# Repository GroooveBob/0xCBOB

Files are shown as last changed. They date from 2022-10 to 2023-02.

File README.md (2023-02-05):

# 0xCBOB
ortho board in static style

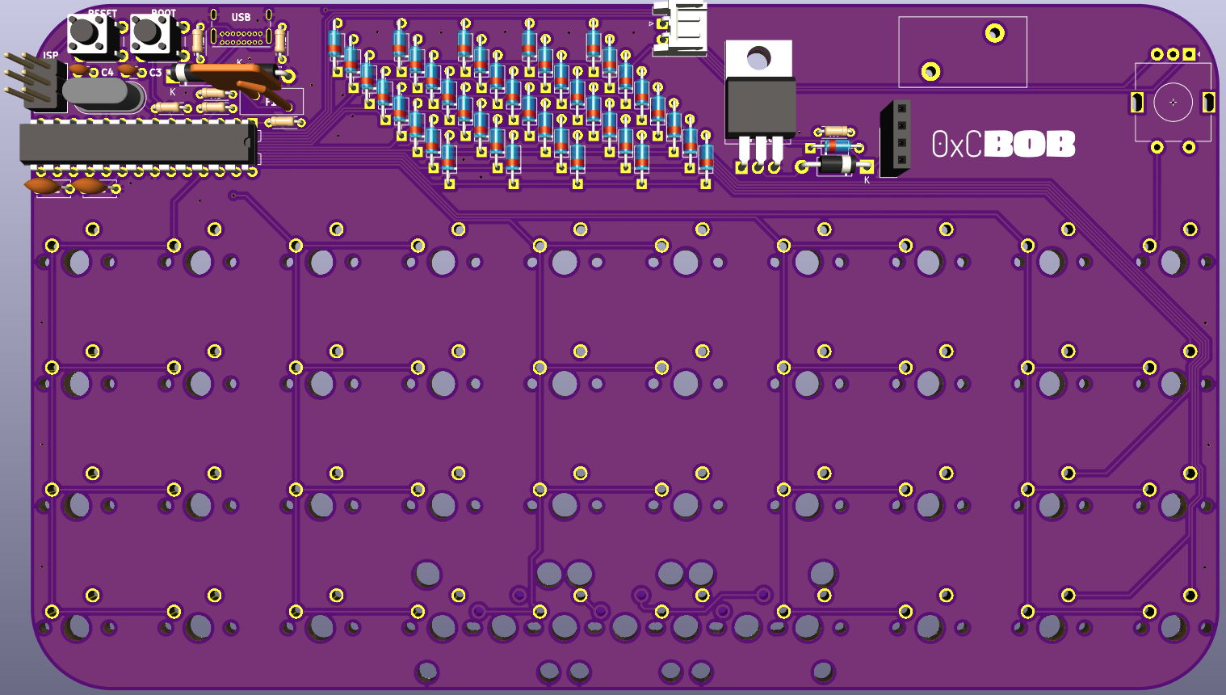
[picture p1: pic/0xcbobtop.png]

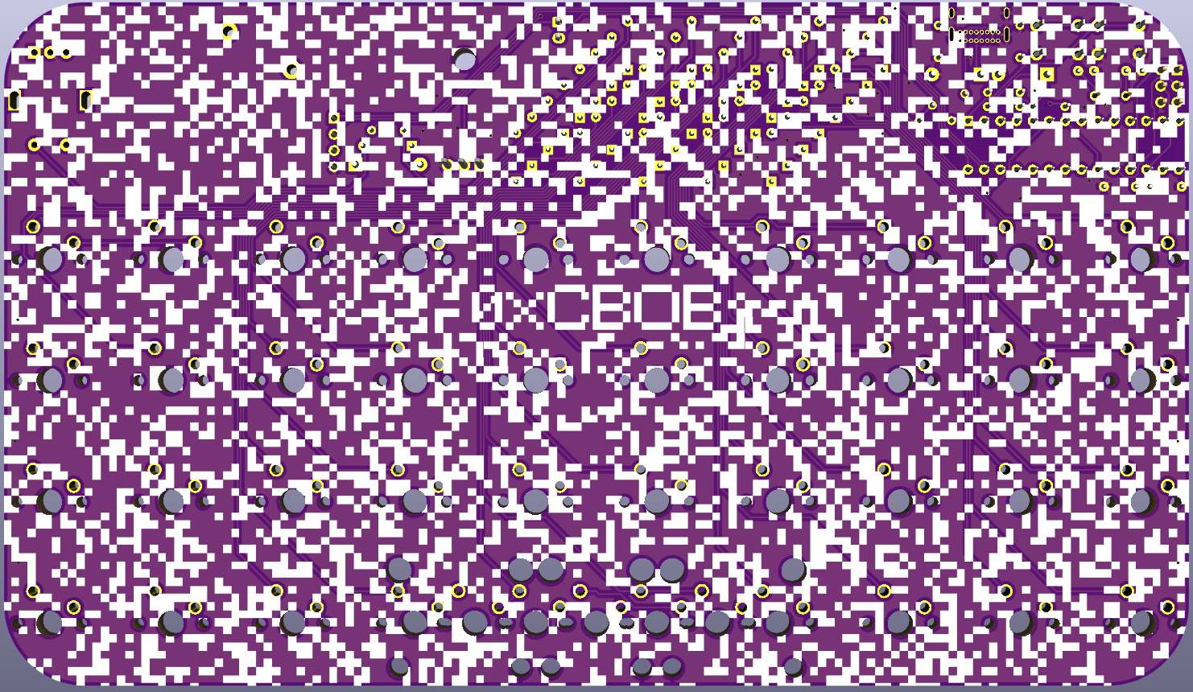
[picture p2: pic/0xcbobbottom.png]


[the wonderful dreipunkteinsvier made the QMK Firmware](https://github.com/dreipunkteinsvier/qmk-config-0xCBOB)

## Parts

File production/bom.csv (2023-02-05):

Designator | Footprint | Quantity | Value | LCSC Part #
SW40 | SW_Cherry_MX_1.00u_PCB | 1 | SW_Push_45deg
D9 | D_DO-35_SOD27_P7.62mm_Horizontal | 1 | 1N4148
SW24 | SW_Cherry_MX_1.00u_PCB | 1 | SW_Push_45deg
D34 | D_DO-35_SOD27_P7.62mm_Horizontal | 1 | 1N4148
SW9 | SW_Cherry_MX_1.00u_PCB | 1 | SW_Push_45deg
SW15 | SW_Cherry_MX_1.00u_PCB | 1 | SW_Push_45deg
SW45 | MXOnly-2U-ReversedStabilizers-NoLED | 1 | SW_Push_45deg
D40 | D_DO-35_SOD27_P7.62mm_Horizontal | 1 | 1N4148
D10 | D_DO-35_SOD27_P7.62mm_Horizontal | 1 | 1N4148
D26 | D_DO-35_SOD27_P7.62mm_Horizontal | 1 | 1N4148
J1 | USB_C_Receptacle_GCT_USB4085 | 1 | USB
C3 | C_Disc_D3.0mm_W1.6mm_P2.50mm | 1 | 20pF
SW32 | SW_Cherry_MX_1.00u_PCB | 1 | SW_Push_45deg
OLED1 | PinSocket_1x04_P2.54mm_Vertical | 1 | OLED
D8 | D_DO-35_SOD27_P7.62mm_Horizontal | 1 | 1N4148
D32 | D_DO-35_SOD27_P7.62mm_Horizontal | 1 | 1N4148
D33 | D_DO-35_SOD27_P7.62mm_Horizontal | 1 | 1N4148
R5 | R_Axial_DIN0204_L3.6mm_D1.6mm_P5.08mm_Horizontal | 1 | 75
SW18 | SW_Cherry_MX_1.00u_PCB | 1 | SW_Push_45deg
R7 | R_Axial_DIN0204_L3.6mm_D1.6mm_P5.08mm_Horizontal | 1 | 2.2K
Y1 | Crystal_HC49-4H_Vertical | 1 | 16MHz
SW27 | SW_Cherry_MX_1.00u_PCB | 1 | SW_Push_45deg
SW34 | SW_Cherry_MX_1.00u_PCB | 1 | SW_Push_45deg
D37 | D_DO-35_SOD27_P7.62mm_Horizontal | 1 | 1N4148
SW31 | SW_Cherry_MX_1.00u_PCB | 1 | SW_Push_45deg
D42 | D_DO-35_SOD27_P7.62mm_Horizontal | 1 | 1N4148
SW12 | SW_Cherry_MX_1.00u_PCB | 1 | SW_Push_45deg
SW43 | MXOnly-2U-ReversedStabilizers-NoLED | 1 | SW_Push_45deg
D20 | D_DO-35_SOD27_P7.62mm_Horizontal | 1 | 1N4148
SW16 | SW_Cherry_MX_1.00u_PCB | 1 | SW_Push_45deg
SW38 | SW_Cherry_MX_1.00u_PCB | 1 | SW_Push_45deg
D11 | D_DO-35_SOD27_P7.62mm_Horizontal | 1 | 1N4148
D31 | D_DO-35_SOD27_P7.62mm_Horizontal | 1 | 1N4148
D2 | D_DO-41_SOD81_P7.62mm_Horizontal | 1 | 1N4729
U1 | DIP-28_W7.62mm | 1 | ATmega328-P
SW21 | SW_Cherry_MX_1.00u_PCB | 1 | SW_Push_45deg
SW3 | SW_Cherry_MX_1.00u_PCB | 1 | SW_Push_45deg
D18 | D_DO-35_SOD27_P7.62mm_Horizontal | 1 | 1N4148
F1 | Fuse_BelFuse_0ZRE0025FF_L9.6mm_W3.8mm | 1 | 500mA
D21 | D_DO-35_SOD27_P7.62mm_Horizontal | 1 | 1N4148
D35 | D_DO-35_SOD27_P7.62mm_Horizontal | 1 | 1N4148
SW39 | SW_Cherry_MX_1.00u_PCB | 1 | SW_Push_45deg
SW5 | SW_Cherry_MX_1.00u_PCB | 1 | SW_Push_45deg
D4 | D_DO-35_SOD27_P7.62mm_Horizontal | 1 | 1N4148
R4 | R_Axial_DIN0204_L3.6mm_D1.6mm_P5.08mm_Horizontal | 1 | 75
D25 | D_DO-35_SOD27_P7.62mm_Horizontal | 1 | 1N4148
SW20 | SW_Cherry_MX_1.00u_PCB | 1 | SW_Push_45deg
D16 | D_DO-35_SOD27_P7.62mm_Horizontal | 1 | 1N4148
SW19 | SW_Cherry_MX_1.00u_PCB | 1 | SW_Push_45deg
SW33 | SW_Cherry_MX_1.00u_PCB | 1 | SW_Push_45deg
SW6 | SW_Cherry_MX_1.00u_PCB | 1 | SW_Push_45deg
MX1 | RotaryEncoder_Alps_EC11E-Switch_Vertical_H20mm | 1 | EC11
D7 | D_DO-35_SOD27_P7.62mm_Horizontal | 1 | 1N4148
SW7 | SW_Cherry_MX_1.00u_PCB | 1 | SW_Push_45deg
SW13 | SW_Cherry_MX_1.00u_PCB | 1 | SW_Push_45deg
SW41 | SW_Cherry_MX_1.00u_PCB | 1 | SW_Push_45deg
D44 | D_DO-41_SOD81_P10.16mm_Horizontal | 1 | 1N4004
D12 | D_DO-35_SOD27_P7.62mm_Horizontal | 1 | 1N4148
SW17 | SW_Cherry_MX_1.00u_PCB | 1 | SW_Push_45deg
D22 | D_DO-35_SOD27_P7.62mm_Horizontal | 1 | 1N4148
SW1 | SW_PUSH_6mm_H5mm | 1 | RESET
SW37 | SW_Cherry_MX_1.00u_PCB | 1 | SW_Push_45deg
D5 | D_DO-35_SOD27_P7.62mm_Horizontal | 1 | 1N4148
D19 | D_DO-35_SOD27_P7.62mm_Horizontal | 1 | 1N4148
D27 | D_DO-35_SOD27_P7.62mm_Horizontal | 1 | 1N4148
D6 | D_DO-35_SOD27_P7.62mm_Horizontal | 1 | 1N4148
SW35 | SW_Cherry_MX_1.00u_PCB | 1 | SW_Push_45deg
C2 | C_Disc_D5.0mm_W2.5mm_P5.00mm | 1 | 0.1uF
R2 | R_Axial_DIN0204_L3.6mm_D1.6mm_P5.08mm_Horizontal | 1 | 5.1K
SW25 | SW_Cherry_MX_1.00u_PCB | 1 | SW_Push_45deg
Q1 | TO-220-3_Horizontal_TabDown | 1 | TIP120
SW8 | SW_Cherry_MX_1.00u_PCB | 1 | SW_Push_45deg
C4 | C_Disc_D3.0mm_W1.6mm_P2.50mm | 1 | 20pF
R1 | R_Axial_DIN0204_L3.6mm_D1.6mm_P5.08mm_Horizontal | 1 | 5.1K
SW26 | SW_Cherry_MX_1.00u_PCB | 1 | SW_Push_45deg
D17 | D_DO-35_SOD27_P7.62mm_Horizontal | 1 | 1N4148
D13 | D_DO-35_SOD27_P7.62mm_Horizontal | 1 | 1N4148
D14 | D_DO-35_SOD27_P7.62mm_Horizontal | 1 | 1N4148
SW4 | SW_Cherry_MX_1.00u_PCB | 1 | SW_Push_45deg
D36 | D_DO-35_SOD27_P7.62mm_Horizontal | 1 | 1N4148
J3 | JST_EH_S2B-EH_1x02_P2.50mm_Horizontal | 1 | Solenoid
SW36 | SW_Cherry_MX_1.00u_PCB | 1 | SW_Push_45deg
D15 | D_DO-35_SOD27_P7.62mm_Horizontal | 1 | 1N4148
SW29 | SW_Cherry_MX_1.00u_PCB | 1 | SW_Push_45deg
D24 | D_DO-35_SOD27_P7.62mm_Horizontal | 1 | 1N4148
D28 | D_DO-35_SOD27_P7.62mm_Horizontal | 1 | 1N4148
D39 | D_DO-35_SOD27_P7.62mm_Horizontal | 1 | 1N4148
R3 | R_Axial_DIN0204_L3.6mm_D1.6mm_P5.08mm_Horizontal | 1 | 1.5k
SW30 | SW_Cherry_MX_1.00u_PCB | 1 | SW_Push_45deg
R6 | R_Axial_DIN0204_L3.6mm_D1.6mm_P5.08mm_Horizontal | 1 | 10k
SW14 | SW_Cherry_MX_1.00u_PCB | 1 | SW_Push_45deg
D41 | D_DO-35_SOD27_P7.62mm_Horizontal | 1 | 1N4148
D38 | D_DO-35_SOD27_P7.62mm_Horizontal | 1 | 1N4148
SW22 | SW_Cherry_MX_1.00u_PCB | 1 | SW_Push_45deg
D30 | D_DO-35_SOD27_P7.62mm_Horizontal | 1 | 1N4148
D29 | D_DO-35_SOD27_P7.62mm_Horizontal | 1 | 1N4148
SW10 | SW_Cherry_MX_1.00u_PCB | 1 | SW_Push_45deg
D43 | D_DO-35_SOD27_P7.62mm_Horizontal | 1 | 1N4148
SW2 | SW_PUSH_6mm_H5mm | 1 | BOOT
D3 | D_DO-35_SOD27_P7.62mm_Horizontal | 1 | 1N4148
SW42 | SW_Cherry_MX_1.00u_PCB | 1 | SW_Push_45deg
SW23 | SW_Cherry_MX_1.00u_PCB | 1 | SW_Push_45deg
SW11 | SW_Cherry_MX_1.00u_PCB | 1 | SW_Push_45deg
D1 | D_DO-41_SOD81_P7.62mm_Horizontal | 1 | 1N4729
C1 | C_Disc_D5.0mm_W2.5mm_P5.00mm | 1 | 0.1uF
D23 | D_DO-35_SOD27_P7.62mm_Horizontal | 1 | 1N4148
SW44 | MXOnly-2U-ReversedStabilizers-NoLED | 1 | SW_Push_45deg
SW28 | SW_Cherry_MX_1.00u_PCB | 1 | SW_Push_45deg

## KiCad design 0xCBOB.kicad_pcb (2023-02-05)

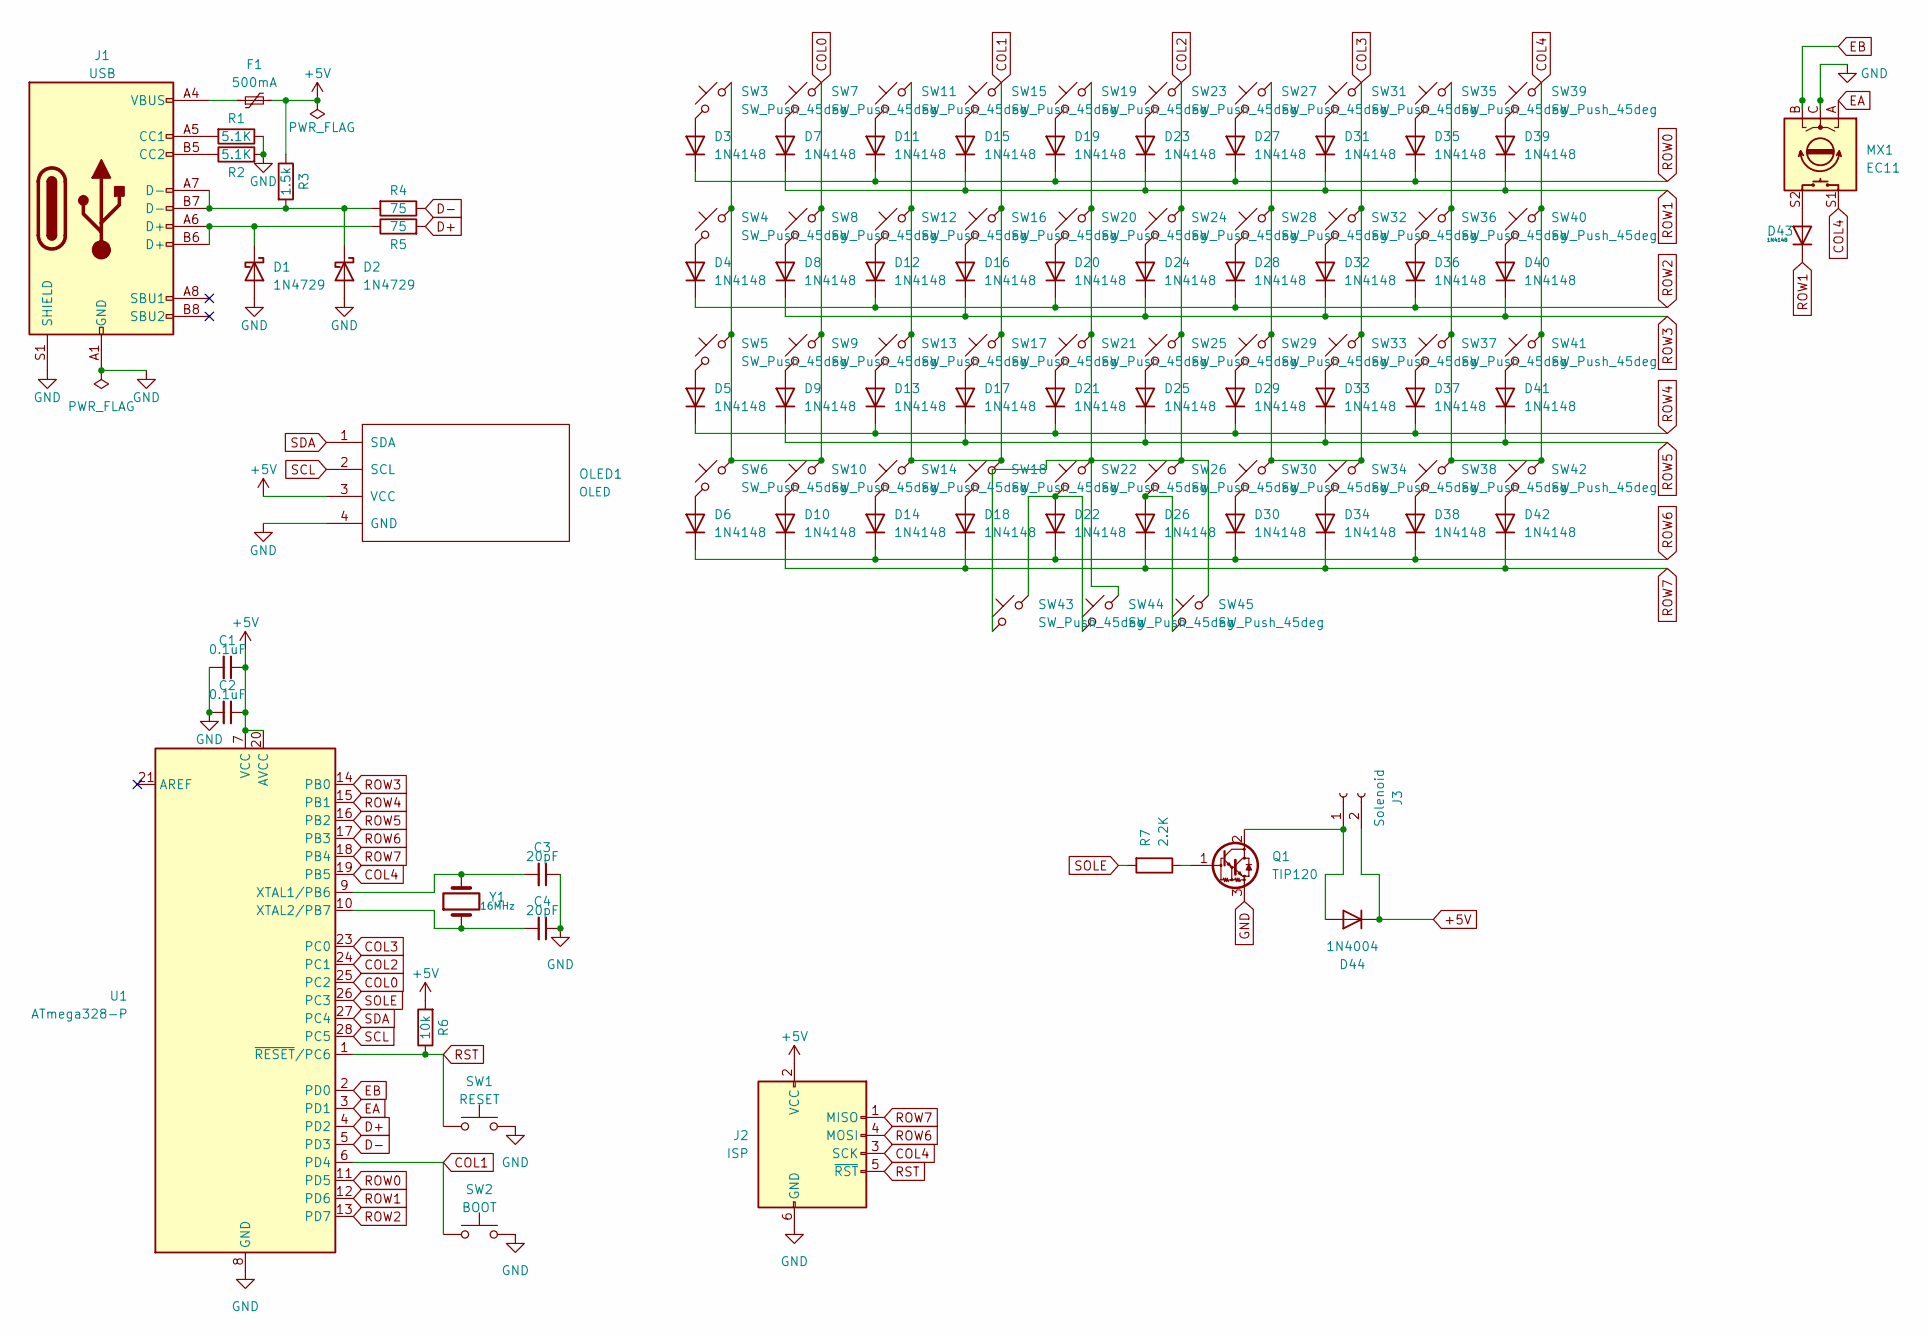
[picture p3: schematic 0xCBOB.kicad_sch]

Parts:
C1, C2: 0.1uF; C_Disc_D5.0mm_W2.5mm_P5.00mm; Part Nb. C277965
C3, C4: 20pF; C_Disc_D3.0mm_W1.6mm_P2.50mm; Part Nb. C254096
D1, D2: 1N4729; D_DO-41_SOD81_P7.62mm_Horizontal; Part Nb. C2532
D3, D4, D5, D6, D7, D8, D9, D10, D11, D12, D13, D14, D15, D16, D17, D18, D19, D20, D21, D22, D23, D24, D25, D26, D27, D28, D29, D30, D31, D32, D33, D34, D35, D36, D37, D38, D39, D40, D41, D42: 1N4148; D_DO-35_SOD27_P7.62mm_Horizontal
D43: 1N4148; D_DO-35_SOD27_P7.62mm_Horizontal; Part Nb. C14538
D44: 1N4004; D_DO-41_SOD81_P10.16mm_Horizontal
F1: 500mA; Fuse_BelFuse_0ZRE0025FF_L9.6mm_W3.8mm; Part Nb. C268799
J1: USB; USB_C_Receptacle_GCT_USB4085; Part Nb. 2073-USB4085-GF-ACT-ND
J2: ISP; PinHeader_2x03_P2.54mm_Vertical
J3: Solenoid; JST_EH_S2B-EH_1x02_P2.50mm_Horizontal
MX1: EC11; RotaryEncoder_Alps_EC11E-Switch_Vertical_H20mm; Part Nb. amz
OLED1: OLED; PinSocket_1x04_P2.54mm_Vertical; Part Nb. amz
Q1: TIP120; TO-220-3_Horizontal_TabDown
R1, R2: 5.1K; R_Axial_DIN0204_L3.6mm_D1.6mm_P5.08mm_Horizontal; Part Nb. C58676
R3: 1.5k; R_Axial_DIN0204_L3.6mm_D1.6mm_P5.08mm_Horizontal; Part Nb. C433494
R4, R5: 75; R_Axial_DIN0204_L3.6mm_D1.6mm_P5.08mm_Horizontal; Part Nb. C713897
R6: 10k; R_Axial_DIN0204_L3.6mm_D1.6mm_P5.08mm_Horizontal; Part Nb. C58673
R7: 2.2K; R_Axial_DIN0204_L3.6mm_D1.6mm_P5.08mm_Horizontal
SW1: RESET; SW_PUSH_6mm_H5mm; Part Nb. C127509
SW2: BOOT; SW_PUSH_6mm_H5mm; Part Nb. C127509
SW3, SW4, SW5, SW6, SW7, SW8, SW9, SW10, SW11, SW12, SW13, SW14, SW15, SW16, SW17, SW18, SW19, SW20, SW21, SW22, SW23, SW24, SW25, SW26, SW27, SW28, SW29, SW30, SW31, SW32, SW33, SW34, SW35, SW36, SW37, SW38, SW39, SW40, SW41, SW42: SW_Push_45deg; SW_Cherry_MX_1.00u_PCB
SW43, SW44, SW45: SW_Push_45deg; MXOnly-2U-ReversedStabilizers-NoLED
U1: ATmega328-P; DIP-28_W7.62mm; Part Nb. C613508
Y1: 16MHz; Crystal_HC49-4H_Vertical; Part Nb. C16212

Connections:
+5V: C1.1, C2.1, D44.1 (K), F1.2, J2.2 (VCC), J3.2, OLED1.3 (VCC), R3.1, R6.2, U1.7 (VCC), U1.20 (AVCC)
COL0: SW3.2, SW4.2, SW5.2, SW6.2, SW7.2, SW8.2, SW9.2, SW10.2, U1.25 (PC2)
COL1: SW2.1, SW11.2, SW12.2, SW13.2, SW14.2, SW15.2, SW16.2, SW17.2, SW18.2, U1.6 (PD4)
COL2: SW19.2, SW20.2, SW21.2, SW22.2, SW23.2, SW24.2, SW25.2, SW26.2, SW43.1, SW44.2, SW45.2, U1.24 (PC1)
COL3: SW27.2, SW28.2, SW29.2, SW30.2, SW31.2, SW32.2, SW33.2, SW34.2, U1.23 (PC0)
COL4: J2.3 (SCK), MX1.S1, SW35.2, SW36.2, SW37.2, SW38.2, SW39.2, SW40.2, SW41.2, SW42.2, U1.19 (PB5)
D+: R5.2, U1.4 (PD2)
D-: R4.1, U1.5 (PD3)
EA: MX1.A, U1.3 (PD1)
EB: MX1.B, U1.2 (PD0)
GND: C1.2, C2.2, C3.1, C4.1, D1.2 (A), D2.2 (A), J1.A1 (GND), J1.A12 (GND), J1.B1 (GND), J1.B12 (GND), J1.S1 (SHIELD), J2.6 (GND), MX1.C, OLED1.4 (GND), Q1.3 (E), R1.1, R2.2, SW1.2, SW2.2, U1.8 (GND), U1.22 (GND)
unnamed: C3.2, U1.9 (XTAL1/PB6), Y1.2
unnamed: C4.2, U1.10 (XTAL2/PB7), Y1.1
unnamed: D1.1 (K), J1.A6 (D+), J1.B6 (D+), R5.1
unnamed: D2.1 (K), J1.A7 (D-), J1.B7 (D-), R3.2, R4.2
unnamed: D3.2 (A), SW3.1
unnamed: D4.2 (A), SW4.1
unnamed: D5.2 (A), SW5.1
unnamed: D6.2 (A), SW6.1
unnamed: D7.2 (A), SW7.1
unnamed: D8.2 (A), SW8.1
unnamed: D9.2 (A), SW9.1
unnamed: D10.2 (A), SW10.1
unnamed: D11.2 (A), SW11.1
unnamed: D12.2 (A), SW12.1
unnamed: D13.2 (A), SW13.1
unnamed: D14.2 (A), SW14.1
unnamed: D15.2 (A), SW15.1
unnamed: D16.2 (A), SW16.1
unnamed: D17.2 (A), SW17.1
unnamed: D18.2 (A), SW18.1
unnamed: D19.2 (A), SW19.1
unnamed: D20.2 (A), SW20.1
unnamed: D21.2 (A), SW21.1
unnamed: D22.2 (A), SW22.1, SW43.2, SW44.1
unnamed: D23.2 (A), SW23.1
unnamed: D24.2 (A), SW24.1
unnamed: D25.2 (A), SW25.1
unnamed: D26.2 (A), SW26.1, SW45.1
unnamed: D27.2 (A), SW27.1
unnamed: D28.2 (A), SW28.1
unnamed: D29.2 (A), SW29.1
unnamed: D30.2 (A), SW30.1
unnamed: D31.2 (A), SW31.1
unnamed: D32.2 (A), SW32.1
unnamed: D33.2 (A), SW33.1
unnamed: D34.2 (A), SW34.1
unnamed: D35.2 (A), SW35.1
unnamed: D36.2 (A), SW36.1
unnamed: D37.2 (A), SW37.1
unnamed: D38.2 (A), SW38.1
unnamed: D39.2 (A), SW39.1
unnamed: D40.2 (A), SW40.1
unnamed: D41.2 (A), SW41.1
unnamed: D42.2 (A), SW42.1
unnamed: D43.2 (A), MX1.S2
unnamed: D44.2 (A), J3.1, Q1.2 (C)
unnamed: F1.1, J1.A4 (VBUS), J1.A9 (VBUS), J1.B4 (VBUS), J1.B9 (VBUS)
unnamed: J1.A5 (CC1), R1.2
unnamed: J1.B5 (CC2), R2.1
unnamed: Q1.1 (B), R7.1
ROW0: D3.1 (K), D11.1 (K), D19.1 (K), D27.1 (K), D35.1 (K), U1.11 (PD5)
ROW1: D7.1 (K), D15.1 (K), D23.1 (K), D31.1 (K), D39.1 (K), D43.1 (K), U1.12 (PD6)
ROW2: D4.1 (K), D12.1 (K), D20.1 (K), D28.1 (K), D36.1 (K), U1.13 (PD7)
ROW3: D8.1 (K), D16.1 (K), D24.1 (K), D32.1 (K), D40.1 (K), U1.14 (PB0)
ROW4: D5.1 (K), D13.1 (K), D21.1 (K), D29.1 (K), D37.1 (K), U1.15 (PB1)
ROW5: D9.1 (K), D17.1 (K), D25.1 (K), D33.1 (K), D41.1 (K), U1.16 (PB2)
ROW6: D6.1 (K), D14.1 (K), D22.1 (K), D30.1 (K), D38.1 (K), J2.4 (MOSI), U1.17 (PB3)
ROW7: D10.1 (K), D18.1 (K), D26.1 (K), D34.1 (K), D42.1 (K), J2.1 (MISO), U1.18 (PB4)
RST: J2.5 (~RST), R6.1, SW1.1, U1.1 (~RESET/PC6)
SCL: OLED1.2 (SCL), U1.28 (PC5)
SDA: OLED1.1 (SDA), U1.27 (PC4)
SOLE: R7.2, U1.26 (PC3)

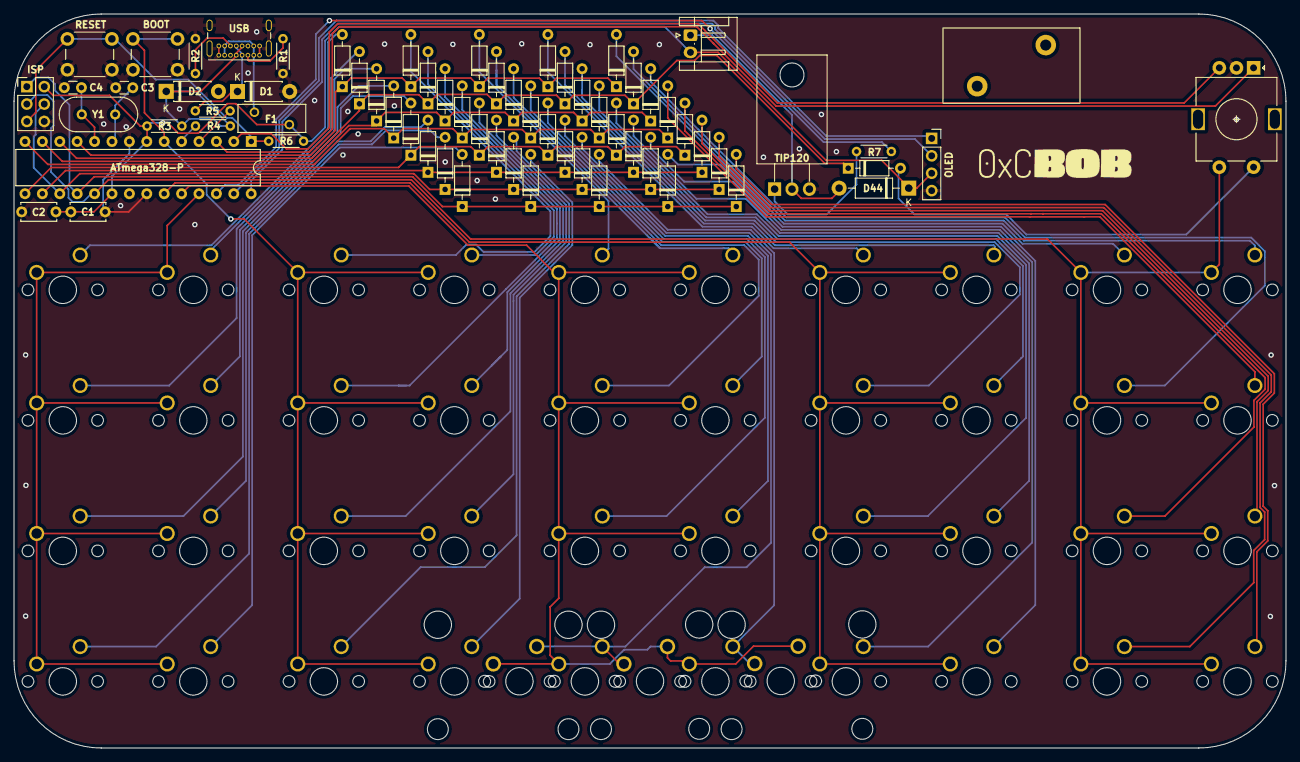
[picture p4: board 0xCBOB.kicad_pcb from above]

Board: 2 copper layers, 185.6 x 107.1 mm, 109 parts (0 on the bottom side), 73 nets.
